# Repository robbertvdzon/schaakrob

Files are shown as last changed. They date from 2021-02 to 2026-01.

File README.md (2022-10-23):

# schaakrob!

# Gebruikte materialen:
nano: https://www.bitsandparts.nl/Arduino-Nano-3.0-Atmega328-5V-16-MHz-(compatible-clone)-p122093
headers voor nano: https://www.bitsandparts.nl/Headerpins-stackable-11mm-16-pins-p119111
4 pins header: https://www.bitsandparts.nl/Header-voor-PCB-4-pins-p101250
4 pin kabel: https://www.bitsandparts.nl/Signaalconnector-Molex-4-polig-met-draad-p113160
3 pin header: https://www.bitsandparts.nl/Header-voor-PCB-3-pins-p101249
3 pin kabel: https://www.bitsandparts.nl/Signaalconnector-Molex-3-polig-met-draad-p113159
2 pin header: https://www.bitsandparts.nl/Header-voor-PCB-2-pins-p101248
2 pin kabel: https://www.bitsandparts.nl/Signaalconnector-Molex-2-polig-met-draad-p113158
grote print plaat: https://www.bitsandparts.nl/Prototyping-board-PCB-(39x63-gaats-10x16cm)-p100969
kleine print plaat: https://www.bitsandparts.nl/Prototyping-board-PCB-(39x19-gaats-10x5cm)-p100967

XRL kabel: https://www.allekabels.nl/xlr-kabel/8/1312747/xlr-kabel.html
XRL chassis: https://www.allekabels.nl/xlr-stekker/69/1601/xlr-chassis-3-polig.html
XRL chassis: https://www.allekabels.nl/xlr-stekker/69/1602/xlr-chassis-3-polig.html

schakelaar: https://www.allekabels.nl/schakelaar/7303/1079540/wipschakelaar.html (max 16A = 2A per motor!)

# Install the rasperry pi:
see /documentation/setup_pi.md

# running on osx:
- brew install stockfish

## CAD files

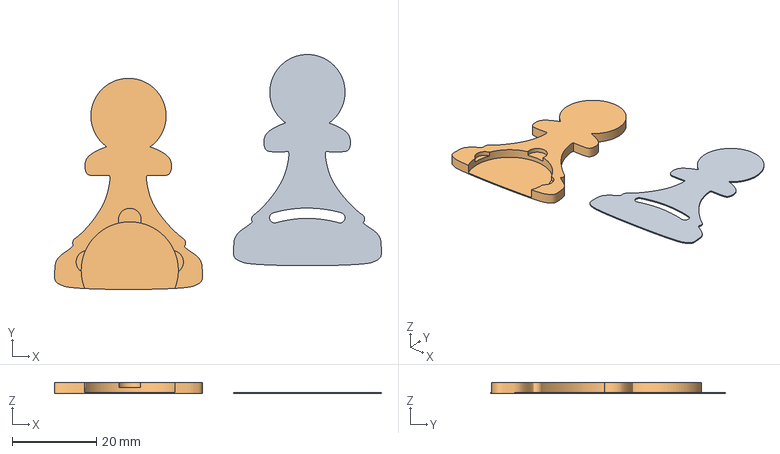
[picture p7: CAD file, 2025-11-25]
3dmodellen/v2/schaakstukken/pion-laag-2.3mf
77.4 x 55.6 x 2.65 mm
pion-top.stl
pion.stl

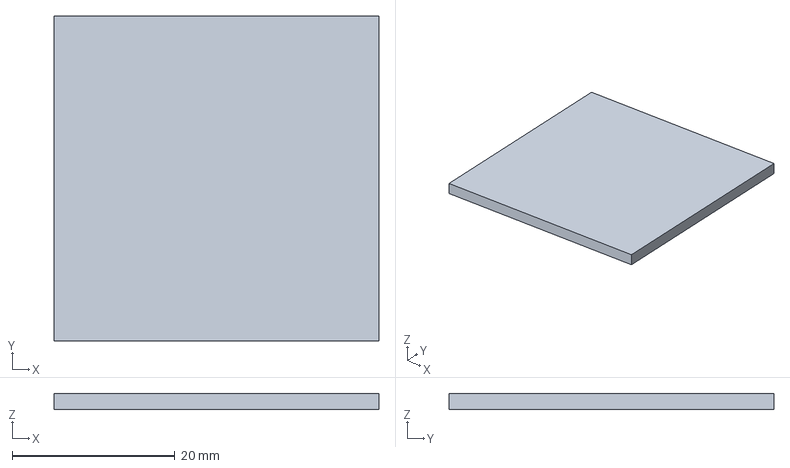
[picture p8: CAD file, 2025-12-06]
3dmodellen/v2/vlak/testvlak-2-kleuren.3mf
40.0 x 40.0 x 2.00 mm

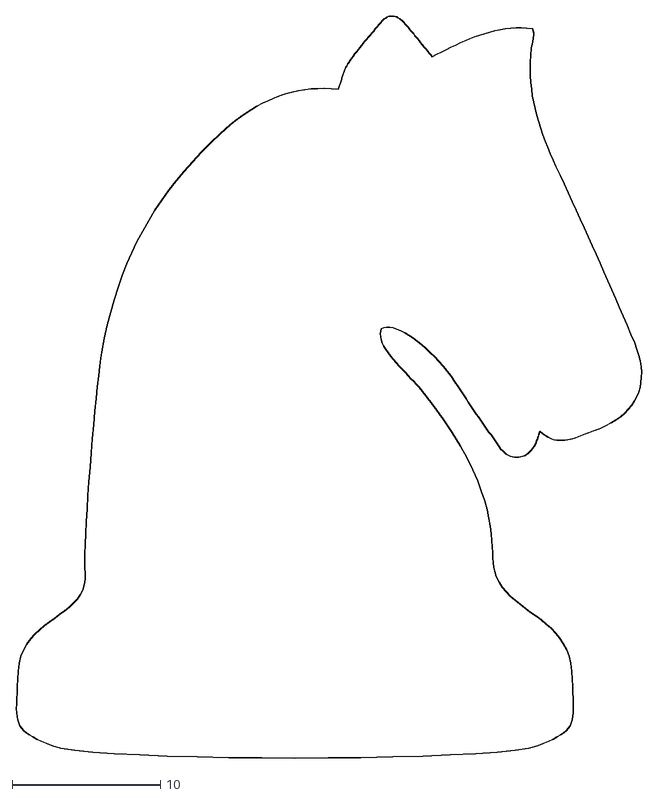
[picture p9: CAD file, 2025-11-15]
3dmodellen/v2/schaakstukken/paard-contour.dxf
42.1 x 50.0

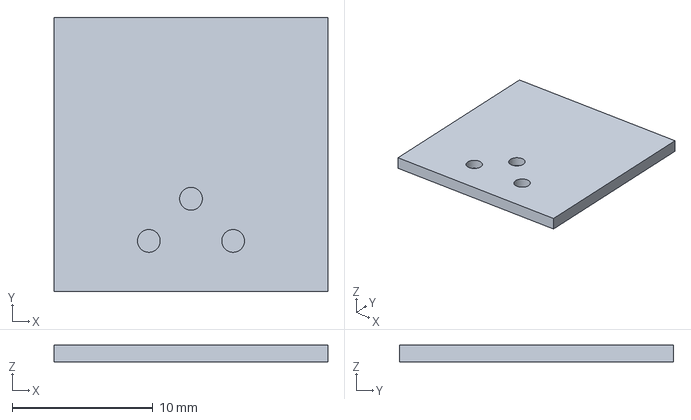
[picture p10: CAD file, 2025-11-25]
3dmodellen/v2/vlak/vlak-30proc.3mf
19.5 x 19.5 x 1.20 mm

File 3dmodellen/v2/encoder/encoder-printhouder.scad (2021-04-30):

difference(){
	union(){
        

        translate([10.5,0,0]){
            cube([7,3,31], center=false);
        }         
        translate([32.5,0,0]){
            cube([7,3,31], center=false);
        }         
        translate([-2,0,31]){
            cube([41.5,2,7], center=false);
        }         
        translate([-2,0,35]){
            cube([10,16.5,3], center=false);
        }         
   
        
   

	}
	union() {
        translate([14,30,5]){
            rotate([90,0,0]){
                cylinder(h=99, r=1.5, $fn=100, center=false);
            }
        }       
        translate([36,30,5]){
            rotate([90,0,0]){
                cylinder(h=99, r=1.5, $fn=100, center=false);
            }
        }       
        translate([2,9.5,0]){
            rotate([0,0,90]){
                cylinder(h=99, r=1.5, $fn=100, center=false);
            }
        }       

  

	}
}

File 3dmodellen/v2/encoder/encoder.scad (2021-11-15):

difference(){
	union(){
        

        translate([10.5,-2,0]){
            cube([7,5,8], center=false);
        }         
        translate([32.5,-2,0]){
            cube([7,5,8], center=false);
        }         


        translate([-2.5,36,0]){
            cube([55,3,5], center=false);
        }         

        translate([0,0,0]){
            cube([50,3,8], center=false);
        }         
        translate([00,36,0]){
            cube([50,3,8], center=false);
        }         
        translate([35/2,0,0]){
            cube([15,3,14], center=false);
        }         
        translate([35/2,36,0]){
            cube([15,3,14], center=false);
        }         

        translate([-4.5,0,0]){
            cube([5,39,2], center=false);
        }         
        translate([49.5,0,0]){
            cube([5,39,2], center=false);
        }         


        translate([25,3,40-1-20-3-2]){
            rotate([90,0,0]){
                cylinder(h=3, r=4, $fn=100, center=false);
            }
        }       
        translate([5,3,40-3-20-7-2]){
            rotate([90,0,0]){
                cylinder(h=3, r=4, $fn=100, center=false);
            }
        }       
        translate([45,3,40-3-20-7-2]){
            rotate([90,0,0]){
                cylinder(h=3, r=4, $fn=100, center=false);
            }
        }   




        translate([25,39,40-1-20-3-2]){
            rotate([90,0,0]){
                cylinder(h=3, r=4, $fn=100, center=false);
            }
        }       
        translate([5,39,40-3-20-7-2]){
            rotate([90,0,0]){
                cylinder(h=3, r=4, $fn=100, center=false);
            }
        }       
        translate([45,39,40-3-20-7-2]){
            rotate([90,0,0]){
                cylinder(h=3, r=4, $fn=100, center=false);
            }
        }   


        // schroefgaten
        translate([-3,35/2+10,0]){
            rotate([0,0,90]){
                cylinder(h=3, r=4, $fn=100, center=false);
            }
        }
    
        translate([53,35/2+10,0]){
            rotate([0,0,90]){
                cylinder(h=3, r=4, $fn=100, center=false);
            }
        }     
   

	}
	union() {

        // assen
        translate([14,30,5]){
            rotate([90,0,0]){
                cylinder(h=99, r=1.2, $fn=100, center=false);
            }
        }       
        translate([36,30,5]){
            rotate([90,0,0]){
                cylinder(h=99, r=1.2, $fn=100, center=false);
            }
        }       

  
        // assen
        translate([25,40,40-1-20-3-2]){
            rotate([90,0,0]){
                cylinder(h=99, r=1.2, $fn=100, center=false);
            }
        }       
        translate([5,40,40-3-20-7-2]){
            rotate([90,0,0]){
                cylinder(h=99, r=1.2, $fn=100, center=false);
            }
        }       
        translate([45,40,40-3-20-7-2]){
            rotate([90,0,0]){
                cylinder(h=99, r=1.2, $fn=100, center=false);
            }
        }   
        // schroefgaten
        translate([-3,35/2+10,-1]){
            rotate([0,0,90]){
                cylinder(h=99, r=2, $fn=100, center=false);
            }
        }
    
        translate([53,35/2+10,-1]){
            rotate([0,0,90]){
                cylinder(h=99, r=2, $fn=100, center=false);
            }
        }     
        

  

	}
}

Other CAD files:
3dmodellen/v2/encoder/encoder-printhouder_small.scad
3dmodellen/v2/encoder/encoder_small.scad
3dmodellen/v2/electra-houder/houder1.scad
3dmodellen/v2/electra-houder/ventilatorhouder.scad
3dmodellen/v2/encoder/encoderwiel.scad
3dmodellen/v2/encoder/encoderwiel2.scad
3dmodellen/v2/encoder/tussenas.scad
3dmodellen/v2/hoekpunten/motorvorm.scad
3dmodellen/v2/hoekpunten/stappenmotorhouder_linksboven.scad
3dmodellen/v2/hoekpunten/stappenmotorhouder_linksonder.scad
3dmodellen/v2/hoekpunten/stappenmotorhouder_rechtsboven.scad
3dmodellen/v2/hoekpunten/stappenmotorhouder_rechtsonder.scad
3dmodellen/v2/oppakkerV8/alles-van-pakker-bij-elkaar.scad
3dmodellen/v2/oppakkerV8/deel2-magneet.scad
3dmodellen/v2/oppakkerV8/deel2-magneet2.scad
3dmodellen/v2/oppakkerV8/printplaathouderv4-deel1.scad
3dmodellen/v2/oppakkerV8/printplaathouderv4-deel3.scad
3dmodellen/v2/oppakkerV8/schuifcontact-horizontaal.scad
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

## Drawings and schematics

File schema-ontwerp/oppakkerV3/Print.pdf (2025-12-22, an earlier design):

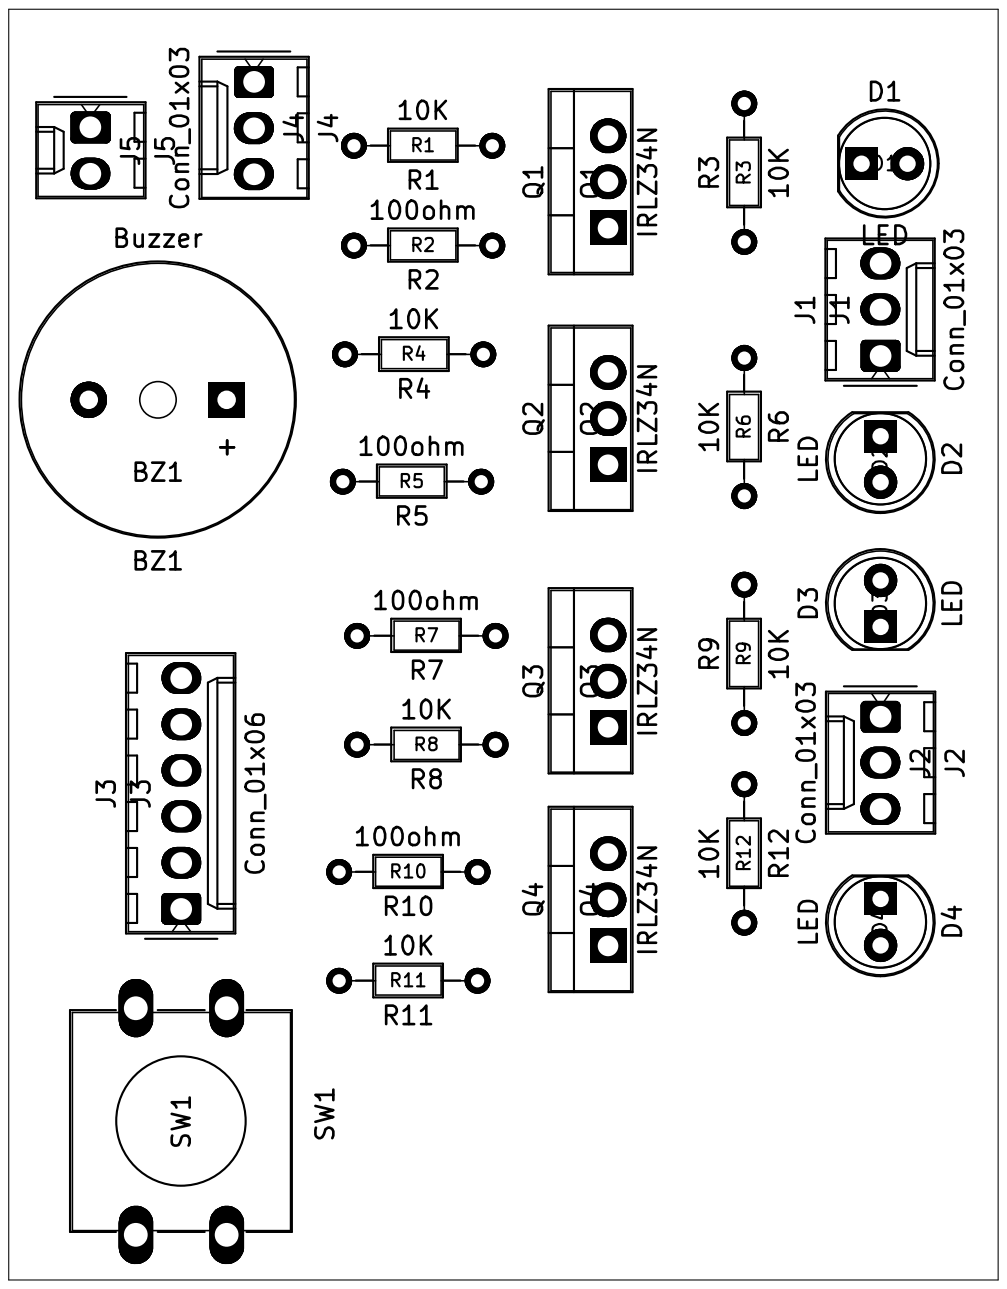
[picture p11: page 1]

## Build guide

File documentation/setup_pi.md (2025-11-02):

# Install pi:
https://www.raspberrypi.com/software/
Download and run  Raspberry Pi Imager on osx
Choose OS: “Raspberry PI OD (32 bit)” <--- Not 64 bit, otherwise pi4j will nog work!
Before writting, edit the settings:
    set hostname: schaakrobot
    enable ssh
    select 'User password authentication'
    set username: pi
    set password: xxx
    set wifi ssid and password
Write to SD card

Find ip address of pi with a keyboard and monitor attached, or use your router admin page.

ssh-copy-id pi@192.168.178.88
ssh pi@192.168.178.88
sudo raspi-config
choose: 3 Interface Options, and enable: i2c and SPI

# Update the system:
sudo apt-get update
sudo apt-get upgrade
sudo rpi-update

# Install i2c modules 
sudo modprobe i2c-dev
sudo modprobe i2c-bcm2708

# Install java:
wget https://mirrors.huaweicloud.com/java/jdk/8u202-b08/jdk-8u202-linux-arm32-vfp-hflt.tar.gz
tar -xzf jdk-8u202-linux-arm32-vfp-hflt.tar.gz
sudo mv jdk1.8.0_202 /opt/java8
echo 'export JAVA_HOME=/opt/java8' >> ~/.bashrc
echo 'export PATH=$JAVA_HOME/bin:$PATH' >> ~/.bashrc
source ~/.bashrc
sudo ln -s /opt/java8/bin/java /usr/bin/java
(note, we need java8. Later versions are not supported by the used pi4j library)

# build pi4j native lib
cd ~
git clone https://github.com/WiringPi/WiringPi --branch master --single-branch wiringpi
cd ~/wiringpi
sudo ./build

# install stockfish and expect:
sudo apt-get install -y expect
sudo apt-get install stockfish

# Install schaakrob:
mkdir ~/git
cd ~/git
git clone https://github.com/robbertvdzon/schaakrob

# Initial build and run the code:
mkdir ~/git/schaakrob/target
cd ~/git/schaakrob
./update_and_run.sh

# Add the folling to  "crontab -e"
@reboot sh /home/pi/ui.sh

# Create /home/pi/ui.sh:
#!/bin/sh
echo startting >> /tmp/schaak.log
FILE=/tmp/rebuildui
cd /home/pi/git/schaakrob
while :
do
if test -f "$FILE"; then
echo "rebuild"
sudo /usr/bin/git pull
sudo ./mvnw package
rm $FILE
fi
java -jar schaakrob-server/target/schaakrob-server-1.0-shaded.jar >> /tmp/robot.log  2>&1
sleep 2
done

# Change permissions:
chmod a+x /home/pi/ui.sh

# After starting the server for the first time: fill in the calibration in the 'manual' section
A8: 16470,13130
H1: 4420,900
A11:2200,13000
H10: 400,850
A21: 20410,12700
H20:18600,450
Pakker hoogte: -1900
Snelheid: 0.8

# optional: check i2c status
sudo i2cdetect -y -a 1

# enable bluetooth (todo: dit moet bij het opstarten gebeuren)
sudo rfkill unblock bluetooth
sudo hciconfig hci0 up

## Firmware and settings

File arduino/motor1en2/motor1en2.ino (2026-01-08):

/*

verschil met v1:
tijdens homen: motor altijd aan
tijdens niet-homen: bij homesensor==1 : zet motor in error


---
i2c protocol:
byte 0 : altijd ^
byte 1 : command (H = home, M = move)
byte 2 : to_pos (6 lang, max 999999)
byte 3 : to_pos 
byte 4 : to_pos 
byte 5 : to_pos 
byte 6 : to_pos 
byte 7 : to_pos 
byte 8: vertragings_factor (in percentage, dus 0135 = 1,35 keer zo snel, dus alle delays vermenigvuldigen met 1,35)
byte 9: vertragings_factor
byte 10: vertragings_factor
byte 11: vertragings_factor

states:
0: homing needed
1: ready
2: moving
3: homing
4: error (out of range)

send: state + pos

*/

#include <Wire.h>

#define NR_OF_BYTES_TO_READ 12

#define HOMING_NEEDED 9
#define READY 1
#define MOVING 2
#define HOMING 3
#define IN_ERROR 4
#define GOING_TO_SLEEP 5
#define SLEEPING 6
#define FATAL_ERROR 7

// #define MIN_STEP_TIME 30

#define HOME_SPEED 250
#define HOME_SPEED_SLOW 500 //500

#define dirPin 3
#define stepPin 4
#define stepPin2 5
#define stepsPerRevolution 2000
#define arm1SensorPin 6
#define arm2SensorPin 8
#define enableMotorPin 12
#define errorPin 9
#define adressPin1 10
#define fanPin 11
#define encoderPin1 2
#define encoderPin2 7

// vrije pinnen: 0,1,2,7 (eventueel pin 10 of 11)

char command;
int requestedPos;
int vertraginsfactor;

char number[50];
int state = HOMING_NEEDED;
int readPos = 0;
int currentPos = 0;
int arm1State = 0;
int currentDir = -1;
int newDir = 0;
int turn = 0;
int homeFinished = 0;
bool error = 0;

int SLAVE_ADDRESS = 6;

// onderstaande 3 consts in gegenereerd in java
static const int delayList[] = {539,384,314,272,244,223,206,193,182,173,165,158,151,146,141,136,132,129,125,122,119,116,114,111,109,107,105,103,101,100,98,96,95,93,92,91,90,88,87,86,85,84,83,82,81,80,79,79,78,77,76,76,75,74,73,73,72,71,71,70,70,69,69,68,67,67,66,66,65,65,65,64,64,63,63,62,62,62,61,61,60,60,60,59,59,59,58,58,58,57,57,57,56,56,56,55,55,55,55,54,54,54,54,53,53,53,52,52,52,52,52,51,51,51,51,50,50,50,50,50,49,49,49,49,49,48,48,48,48,48,47,47,47,47,47,47,46,46,46,46,46,46,45,45,45,45,45,45,44,44,44,44,44,44,44,43,43,43,43,43,43,43,42,42,42,42,42,42,42,42,41,41,41,41,41,41,41,41,40,40,40,40,40,40,40,40,40};
static const int delayArraySize = 187;
static const int indexSteps = 100;
void setup() {

  pinMode(stepPin, OUTPUT);
  pinMode(stepPin2, OUTPUT);
  pinMode(dirPin, OUTPUT);
  pinMode(enableMotorPin, OUTPUT);
  pinMode(errorPin, OUTPUT);

  pinMode(arm1SensorPin, INPUT);
  pinMode(arm2SensorPin, INPUT);
  pinMode(fanPin, OUTPUT);

  pinMode(adressPin1, INPUT);
//  pinMode(adressPin2, INPUT);

  pinMode(encoderPin1, INPUT);
  pinMode(encoderPin2, INPUT);


  digitalWrite(arm1SensorPin, HIGH); // turn on pull-up
  digitalWrite(arm2SensorPin, HIGH); // turn on pull-up
  digitalWrite(encoderPin1, HIGH); // turn on pull-up
  digitalWrite(encoderPin2, HIGH); // turn on pull-up


  boolean addr1 = digitalRead(adressPin1);
  if (addr1) SLAVE_ADDRESS = SLAVE_ADDRESS+1;


  Serial.begin(9600);
  Serial.print("Slave on adress:");
  Serial.println(SLAVE_ADDRESS);

  Wire.begin(SLAVE_ADDRESS);
  Wire.onReceive(receiveData);
  Wire.onRequest(sendData);

  // show that we have been restarted
  bootSeq();

  // reset the pins
  digitalWrite(dirPin, LOW);
  digitalWrite(stepPin, LOW);
  digitalWrite(stepPin2, LOW);
  digitalWrite(enableMotorPin, HIGH);// motors uit bij starten
  digitalWrite(errorPin, LOW);

// fan aan
  digitalWrite(fanPin, HIGH);
  delay(3000);
  digitalWrite(fanPin, LOW);

// test home
//  home1(HOME_SPEED);
   // testAll();


}

void testAll(){

  digitalWrite(enableMotorPin, LOW);
  error = false;
  digitalWrite(dirPin, LOW);



  beepLong();
  Serial.print("test move side1");
  for (int i = 0; i < 8000; i++) {
    pulse(stepPin, -1, 120);
  }
  beepLong();
  Serial.print("test move side2");
  for (int i = 0; i < 8000; i++) {
    pulse(-1, stepPin2, 120);
  }
  beepLong();

  Serial.print("read");
  while (true){
    boolean s1 = digitalRead(arm1SensorPin);
    boolean s2 = digitalRead(arm2SensorPin);
    boolean s3 = digitalRead(encoderPin1);
    boolean s4 = digitalRead(encoderPin2);
    Serial.print(s1);
    Serial.print(s2);
    Serial.print(s3);
    Serial.println(s4);
    delay(200);
  }



}

void loop() {
  /*
  int homeSensorOn = digitalRead(arm1SensorPin);
  int topSensorOn = digitalRead(arm2SensorPin);
  Serial.print(homeSensorOn);
  Serial.print(" ");
  Serial.print(topSensorOn);
  Serial.println("");
      delay(300);
      */

  processCommand();
  checkError();
}

void sendData(){
  if (error){
    Wire.write(IN_ERROR);
  }
  else{
    Wire.write(state);
  }
}

void receiveData(int byteCount){
  while(Wire.available()) {
    processCharRead(Wire.read());
  }
}

void processCharRead(char c){
  if (c == '^'){
    readPos = 0;
  }

  if (readPos < NR_OF_BYTES_TO_READ){
    number[readPos] = c;
    number[readPos+1] = '\0';
  }

  readPos ++;
  if (readPos == NR_OF_BYTES_TO_READ){
    parseCommand();
  }
}


void parseCommand(){
  Serial.print("parseCommand:");
  Serial.println(number);

  char buffer[7];

  buffer[0] = number[2];
  buffer[1] = number[3];
  buffer[2] = number[4];
  buffer[3] = number[5];
  buffer[4] = number[6];
  buffer[5] = number[7];
  buffer[6] = '\0';
  int toPos = atoi(buffer);

  buffer[0] = number[8];
  buffer[1] = number[9];
  buffer[2] = number[10];
  buffer[3] = number[11];
  buffer[4] = '\0';
  vertraginsfactor = atoi(buffer);
  if (vertraginsfactor<10){
    vertraginsfactor = 10;
  }


  requestedPos = toPos;
  command = number[1];

  Serial.print("- cmd:");Serial.println(command);
  Serial.print("- pos:");Serial.println(requestedPos);
  Serial.print("- vertraginsfactor:");Serial.println(vertraginsfactor);
  Serial.print("- currentPos:");Serial.println(currentPos);
}

void processCommand(){
 if (command == 'H') home1(HOME_SPEED);
 if (command == 'M') move();
 if (command == 'X') sleeping();
 if (command == 'B') bootsound();
}

void home1(int homeSpeed){
  if (state == FATAL_ERROR) return;
  state = HOMING;
  Serial.println("home");
  Serial.print("cmd:");Serial.println(command);
  Serial.print("pos:");Serial.println(requestedPos);
  home(homeSpeed);
  state = READY;
  command = '-';
}

void move(){
  if (state == FATAL_ERROR) return;

  if (state == HOMING_NEEDED){
    home1(HOME_SPEED_SLOW);
  }
  if (state == SLEEPING){
    home1(HOME_SPEED_SLOW);
  }

  Serial.println("Start moving");
  if (state!=GOING_TO_SLEEP){
    state = MOVING;
  }

  if (requestedPos>currentPos){
    moveUp(requestedPos);
  }
  else{
    moveDown(requestedPos);
  }

  if (state!=GOING_TO_SLEEP){
    state = READY;
  }
  command = '-';

}

void checkError(){

  if (state == HOMING) return;
  if (state == GOING_TO_SLEEP) return;
  if (state == SLEEPING) return;
  if (state == FATAL_ERROR) return;

  boolean homeSensorOn = digitalRead(arm1SensorPin)==0 && currentPos>100;
  boolean topSensorOn = digitalRead(arm2SensorPin)==0 && currentPos>100;

  if (!homeSensorOn && !topSensorOn){
    if (error){
      Serial.println("Error fixed");
      error = false;
    }
  }
  else if (!error){
    Serial.print("Entering error mode while in state:");
    Serial.println(state);

    Serial.print("homeSensorOn=");
    Serial.println(homeSensorOn);
    Serial.print("topSensorOn=");
    Serial.println(topSensorOn);
    Serial.print("sensor1=");
    Serial.println(digitalRead(arm1SensorPin));
    Serial.print("sensor2=");
    Serial.println(digitalRead(arm2SensorPin));
    Serial.print("currentPos=");
    Serial.println(digitalRead(currentPos));


    error = true;
    state = HOMING_NEEDED;
    digitalWrite(enableMotorPin, HIGH);
    command = '-';
    errorMessage();
  }

}

void moveUp(int reqPos){
  Serial.println("MOVE UP");
  digitalWrite(enableMotorPin, LOW);
  digitalWrite(dirPin, HIGH);
  boolean succeeded = moveNrSteps(reqPos - currentPos, +1);
  if (!succeeded){
    Serial.println("HOME SLOW");
    state = HOMING;
    home(HOME_SPEED_SLOW);
    Serial.println("FINISHED HOME, MOVE AGAIN");
    state = MOVING;
    digitalWrite(dirPin, HIGH);
    succeeded = moveNrSteps(reqPos - currentPos, +1);
    if (!succeeded){
       Serial.println("FAILED AGAIN: FATAL ERROR");
       state = FATAL_ERROR;
    }
  }}

void moveDown(int reqPos){
  Serial.println("MOVE DOWN");
  digitalWrite(enableMotorPin, LOW);
  digitalWrite(dirPin, LOW);
  boolean succeeded = moveNrSteps(currentPos - reqPos, -1);
  if (!succeeded){
    Serial.println("HOME SLOW");
    state = HOMING;
    home(HOME_SPEED_SLOW);
    Serial.println("FINISHED HOME, MOVE AGAIN");
    state = MOVING;
    digitalWrite(dirPin, HIGH);
    succeeded = moveNrSteps(reqPos - currentPos, +1);
    if (!succeeded){
       Serial.println("FAILED AGAIN: FATAL ERROR");
       state = FATAL_ERROR;
    }
  }
}

bool moveNrSteps(int totalSteps, int direction){
  long halfway = totalSteps/2;
  int delayIndex = 0;
  int remainingDelayIndex = 0;
  int remainingSteps;
  int pulsesCounted1 = 0;
  int pulsesCounted2 = 0;
  int diffBetweenPulses = 0;
  bool lastEncodeSensorState1 = false;
  bool lastEncodeSensorState2 = false;
  double delay = 0;
  double calculatedDelay = 0;

  long minOverhead = 1000000;
  long maxOverhead = 0;
  long totalOverhead = 0;
  int minCalcDelay = 10000;

  long moveStart = micros();
  for (int i = 0; i < totalSteps; i++) {
    long stepStart = micros();
    if (i % 30 == 0) {
      checkError();
      if (error) return false;
    }

    if (i % 30 == 0) {
      bool currentEncodeSensorState1 = digitalRead(encoderPin1);
      bool currentEncodeSensorState2 = digitalRead(encoderPin2);
      if (currentEncodeSensorState1 != lastEncodeSensorState1) {
        pulsesCounted1++;
        lastEncodeSensorState1 = currentEncodeSensorState1;
      }
      if (currentEncodeSensorState2 != lastEncodeSensorState2) {
        pulsesCounted2++;
        lastEncodeSensorState2 = currentEncodeSensorState2;
      }
    }
    diffBetweenPulses = pulsesCounted1 - pulsesCounted2;

    if (diffBetweenPulses<-3 || diffBetweenPulses>3) {
         Serial.print("ERROR, too much difference: ");
         Serial.print(pulsesCounted1);
         Serial.print("/");
         Serial.println(pulsesCounted2);
         return false;// error status
    }

    if (i % indexSteps == 0) {
      remainingSteps = totalSteps - i;
      delayIndex = i / indexSteps;
      remainingDelayIndex = remainingSteps / indexSteps;
      if (i < halfway && delayIndex < delayArraySize) delay = delayList[delayIndex];
      if (i > halfway && remainingDelayIndex < delayArraySize) delay = delayList[remainingDelayIndex];
      float tmp = delay;
      tmp = tmp * vertraginsfactor;
      tmp = tmp / 100;
      calculatedDelay = (int)tmp;
    }
    pulse(stepPin, stepPin2, calculatedDelay); // verreken vertraging!
    currentPos+=direction;

    long elapsed = micros() - stepStart;

    // De overhead is de tijd die we nodig hadden voor berekeningen + de pulse functie
    // minus de tijd die de pulse functie zelf wachtte (calculatedDelay).
//     long overhead = elapsed - (long)calculatedDelay;
//     if (overhead < minOverhead) minOverhead = overhead;
//     if (overhead > maxOverhead) maxOverhead = overhead;
//    totalOverhead += overhead;
//     if (calculatedDelay < minCalcDelay) minCalcDelay = (int)calculatedDelay;

    long remaining = (calculatedDelay * 2) - elapsed;
//     if (remaining < MIN_STEP_TIME - elapsed) remaining = MIN_STEP_TIME - elapsed;
    if (remaining > 0) {
      delayMicroseconds(remaining);
    }
  }
  Serial.println("Move finished");
  long totalTime = micros() - moveStart;
  Serial.print("Total pulses: "); Serial.println(totalSteps);
  Serial.print("Total time (ms): "); Serial.println(totalTime / 1000);
  Serial.print("Count1:");
  Serial.println(pulsesCounted1);
  Serial.print("Count2:");
  Serial.println(pulsesCounted2);
  Serial.print("Min overhead: "); Serial.println(minOverhead);
  Serial.print("Max overhead: "); Serial.println(maxOverhead);
  Serial.print("Avg overhead: "); Serial.println(totalOverhead / totalSteps);
  Serial.print("Min delay: "); Serial.println(minCalcDelay);

  analogWrite(errorPin, 0);
  return true;
}

void home(int homeSpeed) {
  digitalWrite(enableMotorPin, LOW);
  error = false;

  arm1State = digitalRead(arm1SensorPin)==0;
  Serial.println("\t start homing");


// omhoog tot beide schakelaars uit zijn
  Serial.println("\t move slow up until not high");
  digitalWrite(dirPin, HIGH);
  int p1 = -1;
  int p2 = -1;
  while (digitalRead(arm1SensorPin)==0 || digitalRead(arm2SensorPin)==0){
    long stepStart = micros();
    if (digitalRead(arm1SensorPin)==0) p1 = stepPin; else p1 = -1;
    if (digitalRead(arm2SensorPin)==0) p2 = stepPin2; else p2 = -1;
    pulse(p1, p2, homeSpeed);
    long elapsed = micros() - stepStart;
    long remaining = (homeSpeed * 2) - elapsed;
//     if (remaining < MIN_STEP_TIME - elapsed) remaining = MIN_STEP_TIME - elapsed;
    if (remaining > 0) {
      delayMicroseconds(remaining);
    }
  }

// omlaag tot beide schakelaars uit zijn
  Serial.println("\t move slow down until high");
  digitalWrite(dirPin, LOW);
  while ((!digitalRead(arm1SensorPin)==0) || (!digitalRead(arm2SensorPin)==0)){
    long stepStart = micros();
    if (!digitalRead(arm1SensorPin)==0) p1 = stepPin; else p1 = -1;
    if (!digitalRead(arm2SensorPin)==0) p2 = stepPin2; else p2 = -1;
    pulse(p1, p2, homeSpeed);
    long elapsed = micros() - stepStart;
    long remaining = (homeSpeed * 2) - elapsed;
//     if (remaining < MIN_STEP_TIME - elapsed) remaining = MIN_STEP_TIME - elapsed;
    if (remaining > 0) {
      delayMicroseconds(remaining);
    }
  }

  Serial.println("\t homing finished");
  currentPos = 00;
  command = '-';

}


void sleeping() {
  if (state == FATAL_ERROR) return;
  state = GOING_TO_SLEEP;
  digitalWrite(enableMotorPin, LOW);
  error = false;

  arm1State = digitalRead(arm1SensorPin)==0;
  Serial.println("\t start sleeping");
  Serial.println(vertraginsfactor);

  // move down until high
  Serial.println("\t move fast down until high");
  digitalWrite(dirPin, LOW);

  int delayIndex = 0;
  double delay = 0;
  double calculatedDelay = HOME_SPEED_SLOW;
  int i = 0;
  bool sleepingFinished = false;
  while (!sleepingFinished) {
    long stepStart = micros();
    if (i % 10 == 0) {
      sleepingFinished = digitalRead(arm1SensorPin) == 0;
    }

    pulse(stepPin, stepPin2, calculatedDelay); // verreken vertraging!
    i++;
    long elapsed = micros() - stepStart;
    long remaining = (calculatedDelay * 2) - elapsed;
//     if (remaining < MIN_STEP_TIME - elapsed) remaining = MIN_STEP_TIME - elapsed;
    if (remaining > 0) {
      delayMicroseconds(remaining);
    }
  }

  currentPos = 00;
  digitalWrite(enableMotorPin, HIGH);
  state = SLEEPING;
  command = '-';
}

void bootsound(){
    beepLong();
    beepLong();
    command = '-';
}

void bootSeq(){
    beep();
}

void errorMessage(){
  beepLong();
}

void beepLong(){
    analogWrite(errorPin, 150);
    delay(300);
    analogWrite(errorPin, 0);
    delay(100);
}

void beep(){
    analogWrite(errorPin, 5);
    delay(100);
    analogWrite(errorPin, 0);
    delay(100);
}


void pulse(int pin1, int pin2, long delaytime){
    if (pin1>0) digitalWrite(pin1, LOW);
    if (pin2>0) digitalWrite(pin2, LOW);
//     delayMicroseconds(delaytime);
    delayMicroseconds(3); // een puls van 2 micro seconde is genoeg voor de stappenmotor driver
    if (pin1>0) digitalWrite(pin1, HIGH);
    if (pin2>0) digitalWrite(pin2, HIGH);
}

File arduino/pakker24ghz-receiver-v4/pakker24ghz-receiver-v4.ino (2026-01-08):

#include <Arduino.h>
#include <WiFi.h>
#include <WebSocketsServer.h>
#define buzzerpin 2
#define switchpin 6
#define pull1 3//4
#define pull2 7
#define magnet1 5//3
#define magnet2 4


const byte address[6] = "00002";
const int TIMEOUT_MAGNET = 20000;

const int MAGNET_OFF = 0;
const int MAGNET_ON = 255;
const int MAGNET_HOLD = 220;

// WiFi configuration
const char* WIFI_SSID = "robbertkarenziggo";
const char* WIFI_PASSWORD = "Robbert12345!";
IPAddress local_IP(192, 168, 178, 10);
IPAddress gateway(192, 168, 178, 1);
IPAddress subnet(255, 255, 255, 0);

WebSocketsServer ws(81);   // WebSocket server op poort 81
volatile bool isBusy = false;
int moveCount = 0;   // houdt aantal uitgevoerde moves bij

// Forward declarations for action functions so we can reference them in server handlers
void pak1();
void pak2();
void zet1();
void zet2();
void connectedBeep();
void beep();
void testloop();

// Helper to run an action if not busy; else reply "buzy"
void handleAction(void (*action)(), uint8_t num) {
  if (isBusy) {
    ws.sendTXT(num, "buzy");
    return;
  }
  isBusy = true;
  action();
  moveCount++;
  isBusy = false;
  // WebSocketsServer::sendTXT in sommige versies verwacht een niet-const String&,
  // dus we vermijden het doorgeven van een tijdelijke String.
  String payload = String(moveCount);
  ws.sendTXT(num, payload);
}

void setup() {
  Serial.begin(9600);

  pinMode(pull1, OUTPUT);
  pinMode(pull2, OUTPUT);
  pinMode(magnet1, OUTPUT);
  pinMode(magnet2, OUTPUT);
  pinMode(buzzerpin , OUTPUT);
  pinMode(switchpin , INPUT_PULLUP);

  // Configureer PWM frequentie voor de magneten (Nano ESP32 specifiek)
  // Dit voorkomt het piepende geluid door de frequentie boven het hoorbare gebied te zetten.
  ledcAttach(magnet1, 25000, 8); // 25 kHz, 8-bit resolutie
  ledcAttach(magnet2, 25000, 8);

  startBeep();

//alles uit
  analogWrite(magnet1, MAGNET_OFF);
  analogWrite(magnet2, MAGNET_OFF);
  digitalWrite(pull1, LOW);
  digitalWrite(pull2, LOW);
  digitalWrite(buzzerpin, LOW);





  // TCCR2B = TCCR2B & B11111000 | B00000001; // for PWM frequency of 31372.55 Hz, avoind zooming of the magnet

  Serial.println("Start wifi");

  // Connect to WiFi with static IP
  WiFi.mode(WIFI_STA);
  // Reduce latency by disabling WiFi modem sleep (avoids 100–300ms wake delays)
  WiFi.setSleep(false);
  if (!WiFi.config(local_IP, gateway, subnet)) {
    Serial.println("WiFi config failed");
  }
  WiFi.begin(WIFI_SSID, WIFI_PASSWORD);
  Serial.print("Connecting to WiFi ");
  Serial.print(WIFI_SSID);
  int tries = 0;
  while (WiFi.status() != WL_CONNECTED && tries < 100) { // ~10 seconds
    shortDelay(100);
    Serial.print(".");
    tries++;
  }
  Serial.println();
  if (WiFi.status() == WL_CONNECTED) {
    Serial.print("WiFi connected. IP: ");
    Serial.println(WiFi.localIP());
    beepLong();
  } else {
    Serial.println("WiFi NOT connected yet; continuing and web server will start anyway.");
    beepLong();
    beepLong();
    beepLong();
  }

  // WebSocket server starten
  ws.begin();
  // Minimize TCP latency (disable Nagle) if supported by the library version
  ws.onEvent([](uint8_t num, WStype_t type, uint8_t * payload, size_t length){
    if (type == WStype_TEXT) {
      String cmd = String((char*)payload).substring(0, length);
      cmd.trim();
      if (cmd == "pak1") { handleAction(pak1, num); return; }
      if (cmd == "pak2") { handleAction(pak2, num); return; }
      if (cmd == "zet1") { handleAction(zet1, num); return; }
      if (cmd == "zet2") { handleAction(zet2, num); return; }
      if (cmd == "connected") { handleAction(connectedBeep, num); return; }
      if (cmd == "status") { ws.sendTXT(num, isBusy ? "buzy" : "idle"); return; }
      ws.sendTXT(num, "unknown");
    }
  });
  Serial.println("WebSocket server started");
}



unsigned long lastGrapTime1 = 0;
unsigned long lastGrapTime2 = 0;
unsigned long currentTime = 0;

boolean oldButtonState = true;



void shortDelay(unsigned long ms){
  unsigned long end = millis() + ms;
  while ((long)(end - millis()) > 0) {
    // keep the websocket server responsive during delays
    ws.loop();
    delay(1);
  }
}

void loop() {
  // keep websocket server responsive
  ws.loop();

  boolean buttonState = digitalRead(switchpin);
  if (!buttonState &&  oldButtonState){
    Serial.println("pressed");
    beep();
    testloop();
  }
  oldButtonState = buttonState;

  currentTime = millis();
/*
 if (lastGrapTime1!=-1 && (currentTime-lastGrapTime1)>TIMEOUT_MAGNET){
    // drop piece
    analogWrite(magnet1, MAGNET_OFF);
    analogWrite(pull1, MAGNET_OFF);
    lastGrapTime1 = -1;
  }
  if (lastGrapTime2!=-1 && (currentTime-lastGrapTime2)>TIMEOUT_MAGNET){
    // drop piece
    analogWrite(magnet2, MAGNET_OFF);
    analogWrite(pull2, MAGNET_OFF);
    lastGrapTime2 = -1;
  }
  */
}


void pak1(){
       digitalWrite(pull1, HIGH);// arm 2
       analogWrite(magnet1, MAGNET_ON);// magneet 2
       shortDelay(100);
       digitalWrite(pull1, LOW);
       shortDelay(100);
       analogWrite(magnet1, MAGNET_HOLD);
       lastGrapTime2 = millis();
}

void pak2(){
       digitalWrite(pull2, HIGH);// arm 2
       analogWrite(magnet2, MAGNET_ON);// magneet 2
       shortDelay(100);
       digitalWrite(pull2, LOW);
       shortDelay(100);
       analogWrite(magnet2, MAGNET_HOLD);
       lastGrapTime2 = millis();
}

void zet1(){
       digitalWrite(pull1, HIGH);// arm 2
       shortDelay(30);
       analogWrite(magnet1, MAGNET_OFF);
       shortDelay(100);
       digitalWrite(pull1, LOW);
       lastGrapTime2 = -1;
}

void zet2(){
       digitalWrite(pull2, HIGH);// arm 2
       shortDelay(30);
       analogWrite(magnet2, MAGNET_OFF);
       shortDelay(100);
       digitalWrite(pull2, LOW);
       lastGrapTime2 = -1;
}


void testloop(){
  Serial.println("testloop start");
  pak1();
  shortDelay(1000);
  zet1();
  shortDelay(1000);
  pak2();
  shortDelay(1000);
  zet2();
  shortDelay(1000);
  Serial.println("testloop stop");

}


void beep(){
    digitalWrite(buzzerpin , HIGH);
    shortDelay(50);
    digitalWrite(buzzerpin , LOW);
    shortDelay(50);
}

void beepLong(){
    digitalWrite(buzzerpin , HIGH);
    shortDelay(500);
    digitalWrite(buzzerpin , LOW);
    shortDelay(500);
}

void connectedBeep(){
  beep();
  beep();
}

void startBeep() {
  beep();
  beep();
  beep();
  beep();
  beep();
  beep();
}

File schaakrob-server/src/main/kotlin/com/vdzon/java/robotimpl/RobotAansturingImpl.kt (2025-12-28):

package com.vdzon.java.robotimpl

import com.pi4j.component.lcd.impl.I2CLcdDisplay
import com.pi4j.io.i2c.I2CBus
import com.pi4j.io.i2c.I2CDevice
import com.pi4j.io.i2c.I2CFactory
import com.pi4j.io.i2c.I2CFactory.UnsupportedBusNumberException
import com.vdzon.java.BerekenVersnelling
import com.vdzon.java.Lock
import com.vdzon.java.robitapi.RobotAansturing
import com.vdzon.java.schaakspel.Schaakspel
import org.slf4j.LoggerFactory
import java.io.IOException
import java.io.PrintWriter
import java.net.HttpURLConnection
import java.net.InetAddress
import java.net.NetworkInterface
import java.net.URL
import java.net.UnknownHostException
import java.nio.file.Files
import java.nio.file.Paths
import java.util.Arrays
import java.util.Enumeration
import java.util.function.Consumer
import kotlin.concurrent.thread
import okhttp3.OkHttpClient
import okhttp3.Request
import okhttp3.Response
import okhttp3.WebSocket
import okhttp3.WebSocketListener
import java.util.concurrent.CompletableFuture
import java.util.concurrent.LinkedBlockingQueue
import java.util.concurrent.TimeUnit


private val log = LoggerFactory.getLogger(RobotAansturingImpl::class.java)

// Eenvoudige WebSocket client die 1 outstanding request tegelijk ondersteunt
class OppakkerWsClient(private val url: String) {
    private val client = OkHttpClient.Builder()
        .pingInterval(10, TimeUnit.SECONDS)
        .readTimeout(0, TimeUnit.MILLISECONDS) // stream, geen lees-timeout
        .build()

    @Volatile private var webSocket: WebSocket? = null
    private val responseQueue = LinkedBlockingQueue<CompletableFuture<String>>()

    @Synchronized
    private fun ensureConnected() {
        if (webSocket != null) return
        val request = Request.Builder().url(url).build()
        webSocket = client.newWebSocket(request, object : WebSocketListener() {
            override fun onOpen(ws: WebSocket, response: Response) {
                // noop
            }

            override fun onMessage(ws: WebSocket, text: String) {
                responseQueue.poll()?.complete(text.trim())
            }

            override fun onClosed(ws: WebSocket, code: Int, reason: String) {
                webSocket = null
            }

            override fun onFailure(ws: WebSocket, t: Throwable, response: Response?) {
                webSocket = null
                responseQueue.poll()?.completeExceptionally(t)
            }
        })
    }

    fun sendCommandWaitResult(cmd: String, timeoutMs: Long = 5000): String {
        ensureConnected()
        val ws = webSocket ?: throw IOException("Oppakker WS not connected")
        val fut = CompletableFuture<String>()
        responseQueue.put(fut)
        val sent = ws.send(cmd)
        if (!sent) {
            responseQueue.remove(fut)
            throw IOException("Send failed for command '$cmd'")
        }
        return fut.get(timeoutMs, java.util.concurrent.TimeUnit.MILLISECONDS)
    }
}

private const val OPPAKKER_RETRY_COUNT = 20

class RobotAansturingImpl() : RobotAansturing {

    private var schaakspel: Schaakspel? = null // todo: deze injecteren

    var lastPos1 = 0
    var lastPos2 = 0
    var formattedDelayFactor1 = "0050"
    var formattedDelayFactor2 = "0050"
    private var homeNeeded = false
    private var allReady = false
    private var allSleeping = false
    private var arm1: I2CDevice? = null
    private var arm2: I2CDevice? = null
    private var lastMovement = 0L
    private var arm1AtHome = false
    private var arm2AtHome = false
    private var currentLoopThread: Thread? = null
    private var movingToX: Int = 0
    private var movingToY: Int = 0


    fun init() {
        if (arm1 != null) {
            return
        }

        var initialized = false
        while (!initialized) {
            val display = Display(this)
            display.startDisplay()

            try {
                log.info("Open devices")
                val i2c = I2CFactory.getInstance(I2CBus.BUS_1)
                arm1 = i2c.getDevice(ARM1)
                arm2 = i2c.getDevice(ARM2)
                // test connectoe
                arm1!!.readI2c("arm1")
                arm2!!.readI2c("arm2")



                initialized = true
            } catch (e: UnsupportedBusNumberException) {
                log.info("ERROR, UnsupportedBusNumberException in init")
                Thread.sleep(2000)
            } catch (e: IOException) {
                log.info("ERROR IOException in init:" + e.message)
                Thread.sleep(2000)
            }
        }

        log.info("Devices found")

        thread {
            println("start check sleep thread")
            while (true) {
                Thread.sleep(3000)
                val timeout = System.currentTimeMillis() - 1000 * 60 // 20 seconds
                val bothHome = bothArmsAtHome()
                val hasTimeout = lastMovement < timeout
                if (bothHome && hasTimeout) {
                    println("automatically sleep!")
                    sleep()
                }
            }
        }
    }

    fun callOppakker(actie: String) {
        println("CALL OPPAKKER: $actie")
        var retryCount = 0
        while (true) {
            try {
                val response = oppakkerWs.sendCommandWaitResult(actie, timeoutMs = 5000)
                println("Oppakker response: '$response' for actie='$actie'")

                if (response == "buzy") {
                    Thread.sleep(100)
                    continue
                }
                val newPakkerCount = response.toLong()
                val oldPakkerCount = Statistics.getLastPickCount()
                if (newPakkerCount <= oldPakkerCount) {
                    Statistics.pickerRestartDetected()
                }
                Statistics.setLastPickCount(newPakkerCount)
                Statistics.addPick()
                return
            } catch (e: NumberFormatException) {
                throw IOException("Unexpected non-numeric response from oppakker", e)
            } catch (e: Exception) {
                retryCount++
                if (retryCount >= OPPAKKER_RETRY_COUNT) {
                    throw RuntimeException("Oppakker down detected (after $OPPAKKER_RETRY_COUNT retries)")
                }
                System.err.println("Error calling oppakker via WS: ${e.message}")
                Thread.sleep(1000)
            }
        }
    }


    fun httpGet(urlStr: String): String {
        val url = URL(urlStr)
        val conn = (url.openConnection() as HttpURLConnection).apply {
            requestMethod = "GET"
            connectTimeout = 3000
            readTimeout = 5000
        }

        return conn.inputStream.bufferedReader().use { it.readText().trim() }
    }

    // WebSocket client naar de oppakker (ESP32/ESP8266)
    private val oppakkerWs = OppakkerWsClient("ws://192.168.178.10:81/")


    fun setSchaakspel(schaakspel: Schaakspel) {
        this.schaakspel = schaakspel
    }
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

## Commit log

2021-02-02 hoekpunten 3d modellen
    [motorvorm.scad, stappenmotorhouder-A.scad, stappenmotorhouder-B.scad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]
2021-02-07 update 3d models
    [dame-top.scad, dame.scad, grafiethouder-deksel.scad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]
2021-02-23 update 3d modellen
    [deksel.scad, deksel1.scad, deksel2.scad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]
2021-02-26 versie met 8 motoren
    [dame-top.scad, dame.scad, deksel.scad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]
2021-03-06 eerste versie met i2c display
2021-03-12 Wait for devices to be ready
    [houder1.scad]
2021-03-21 ook buitenste vlakken kunnen gebruiken
    [toren.scad]
2021-03-27 handmatig magneten kunnen aansturen
    [oppakker-rand.scad]
2021-03-30 update printjes
    [deksel-met-schakelaarstaaf-en-schuifcontact.scad, kabel-montage.scad, kapje-voor-schuifcontacten .scad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]
2021-04-02 extra logging, goed omgaan bij i2c fouten
2021-04-06 fix arduino code
2021-06-01 2e pakker
    [jeroen.scad, jeroen2.scad, jeroen3.scad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]
